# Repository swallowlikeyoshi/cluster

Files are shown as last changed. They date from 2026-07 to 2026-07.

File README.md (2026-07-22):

# HEVEN Cluster 펌웨어

**2026 영광 대회 · 계기 클러스터(Instrument Cluster)** — ESP32가 CAN/BLE로 차량 상태(속도·전압·SOC·온도·에러)를 **받아서** LCD에 표현하고, 계기판 버튼 입력을 VCU로 보냅니다. VESS 신호 경로와 스위칭은 클러스터 ESP32 GPIO 입력에서 분리합니다. VCU와 달리 **안전 임계가 약한 표시 전용 보드**입니다.

> 🤖 **AI 에이전트/팀원은 [`AGENTS.md`](AGENTS.md)를 먼저 읽으세요** — 무엇을 고쳐도 되고 무엇을 건드리면 안 되는지 규칙이 있습니다.

---

## 한눈에

- **스택**: PlatformIO + Arduino-ESP32, TWAI(CAN), ILI9341 LCD. 화면은 **패널 독립적 1bpp 프레임버퍼**(위젯이 그림) + `display_blit`(ILI9341로 blit)
- **구조**: 잠긴 코어(CAN·프레임버퍼·blit) + 팀원이 채우는 순수 모듈(`src/modules/`). VCU와 **동일한 2층 설계**지만 안전 FSM·50ms 라이프 태스크가 없고 CAN은 **수신(RX) 위주**입니다.
- **상태**: ESP32 빌드 그린, 호스트 테스트 39개 통과

## 빠른 시작

```bash
# 1. 이 레포를 깨끗한 위치에 클론
git clone https://github.com/2026-HEVEN/cluster.git
cd cluster

# 2. PlatformIO 설치 (한 번만) — VS Code면 PlatformIO IDE 확장 설치로 대체 가능
uv tool install platformio      # 또는: pipx install platformio

# 3. 노트북에서 테스트 (하드웨어 불필요)
pio test -e native

# 4. 보드에 빌드 & 업로드 (ESP32 연결 상태에서)
pio run -e esp32dev -t upload
```

> 🧪 **테스트가 처음이거나 Windows 사용자라면** → 노션 [펌웨어 테스트 실행 방법](https://www.notion.so/390913e532e68199a9b5e340b73e9e71) 참고. AI에 복붙할 프롬프트 + "이렇게 나오면 성공" 출력 예시 + Windows(WSL2/MinGW) 셋업까지 있습니다. (보드 업로드는 Windows도 그냥 되고, `native` 단위테스트만 host 컴파일러가 필요해요.)

> ℹ️ 모터컨트롤러 값은 MCU→VCU 피드백 프레임을 Cluster가 같은 CAN 버스에서 수신합니다. BMS SOC는 `LWS-1608` BLE BMS에 Cluster ESP32가 직접 연결해 표시용 telemetry로만 읽습니다.

## 어디서 작업하나

| 폴더 | 내용 | 편집? |
|---|---|---|
| `src/modules/` | 순수 계산 함수 `xxx_compute()` | ✅ **여기서만** |
| `test/` | 노트북 단위 테스트 | ✅ |
| `src/core/`, `src/logic/`, `include/` | CAN·framebuffer·display_blit·스케줄러·타입 | 🔒 잠김 |
| `platformio.ini`, `src/main.cpp` | 빌드 설정·진입점 | 🔒 잠김 |

새 모듈을 추가하거나 기존 `compute()`를 채우는 법 → [`docs/ADDING_A_MODULE.md`](docs/ADDING_A_MODULE.md)

## 모듈 목록 (FILL-IN)

- `hmi_input` — config 스위치(패독·TC·회생·디버그) → `ClusterCommand` (CAN으로 VCU에 전송)
- `widgets/` — 계기판 화면 위젯 (speed·battery·warnings·gear ...). 1bpp 프레임버퍼에 그림.
  새 위젯 추가법: `docs/ADDING_A_WIDGET.md`

> 표시는 패널 독립적 **1bpp 프레임버퍼**로. 실제 패널 blit(`display_blit`)은 하드웨어 확정 후 구현.

## 문서

| 문서 | 내용 |
|---|---|
| [`AGENTS.md`](AGENTS.md) / `CLAUDE.md` | 작업 규칙 (에이전트·팀원 필독) |
| [`docs/ADDING_A_MODULE.md`](docs/ADDING_A_MODULE.md) | 모듈 추가/작성 절차 |
| [`docs/CAN_PROTOCOL.md`](docs/CAN_PROTOCOL.md) | CAN 메시지 명세 (VCU/Cluster 공유 단일 출처) |

> 전체 설계 원리(compute/update 분리, state 격리, 테스트 등)는 **VCU 레포의 [`ARCHITECTURE.md`](https://github.com/2026-HEVEN/vcu/blob/main/docs/ARCHITECTURE.md)** 와 동일합니다.

## 아직 미구현 (의도된 TODO)

- **VCU 표시 상태 프레임 구현** — VCU가 `0x1801C0D0`으로 확정 기어/HV/브레이크 상태를 보내면 Cluster가 그 값을 우선 표시합니다.
- **BMS BLE 실차 검증** — `LWS-1608` BLE 이름, `FFE0/FFE1/FFE2` 특성, SOC/current 부호를 실제 배터리팩에서 확인해야 합니다.

## 버전 기록 (Changelog)

> 각 버전은 git 태그로도 관리됩니다 → [GitHub Releases](https://github.com/2026-HEVEN/cluster/releases)
> **새 버전 올릴 때:** 아래에 항목 추가 → `git tag vX.Y` → `git push origin vX.Y`.

### v1.1.1 (2026-07-06) — 위젯 레이아웃 렌더 테스트
- `test/test_render_layout`: `app_wiring.cpp`의 위젯 배치를 그대로 재현해 24bit BMP로 덤프하는 시각화 테스트 추가. `pio test -e native -f test_render_layout` 로 실행 → `render_layout.bmp` 생성(Windows 사진 앱/그림판 등 추가 도구 없이 바로 열림), 위젯별 할당 공간을 박스로 표시
- `.gitignore`에 `*.bmp` 추가

### v1.1 (2026-06-29) — 디스플레이 프레임버퍼 재설계
- 패널 독립적 **1bpp 프레임버퍼**(320×160) + 위젯 모듈(speed · battery · warnings · gear) 도입 — 렌더링을 모듈로 넘겨 자유도↑, host 테스트 가능(ASCII 시각화)
- `hmi_input` → **`ClusterCommand`**(paddock · TC · regen · debug) 의미 커맨드 패턴, **패독 모드** 추가
- **제거**: `vess`, `indicators`, `display_render`(U8g2), `io_expander`(MCP23017)
- `display_blit` stub(패널 확정 후 구현), CAN 커맨드 레이아웃(`CAN_PROTOCOL.md` §5.7) 갱신

### v1.0 (2026-06-29) — 초기 Cluster 펌웨어 베이스
- 잠긴 코어(CAN RX · MCP23017 · U8g2 OLED) + 순수 모듈(display · indicators · vess · hmi_input)
- PlatformIO native 테스트, AGENTS/ADDING_A_MODULE/CAN_PROTOCOL 문서

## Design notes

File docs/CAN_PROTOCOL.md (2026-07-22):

# HEVEN CAN 프로토콜 명세서 (단일 출처)

> **이 문서는 VCU·Cluster 양 레포가 공유하는 단일 출처(single source of truth)입니다.**
> 코드(`include/can_protocol.h`)와 이 문서는 항상 일치해야 하며, 수정 시 **양 레포에 동일하게 반영**합니다. (담당: 김도현)
> 출처: `EZkontrol-CANBUS-MCU-to-VCU.pdf V1.0`, `EZkontrol-CANBUS-MCU-to-METER.pdf V1.1`, 시스템 설계.

---

## 1. 버스 파라미터

| 항목 | 값 |
|---|-----|
| 비트레이트 | **250 kbps** |
| 프레임 | CAN 2.0B **확장(29비트) 식별자** |
| 바이트 순서 | **리틀엔디언** (예: 0x1234 → 0x34 먼저, 0x12 나중) |
| 토폴로지 | 데이지체인, 양 끝단 120Ω 종단 |
| 표준 | SAE J1939 기반 |

---

## 2. 29비트 식별자 구조 (J1939)

```
 28..26   25   24   23..16     15..8       7..0
┌────────┬────┬────┬────────┬──────────┬────────────┐
│PRIORITY│ R  │ DP │  PF    │   PS     │     SA     │
│ 3bit   │ 0  │ 0  │ 8bit   │  8bit    │   8bit     │
└────────┴────┴────┴────────┴──────────┴────────────┘
```
- **PRIORITY**: 0~7 (값 작을수록 우선). 제어명령=3, 피드백=6.
- **PF (PDU Format)**: 메시지 종류. PF<240이면 PS=목적지 주소(DA), PF≥240이면 PS=그룹확장.
- **PS**: 목적지 노드 주소 (PF<240일 때).
- **SA**: 송신 노드 주소.

> 예) `0x0C01EFD0` → PRIORITY=3, PF=0x01, PS=0xEF(MCU1 목적지), SA=0xD0(VCU 송신).
> 즉 **"VCU가 MCU1에게 보내는 1번 메시지"**.

---

## 3. 노드 주소 (SA)

### HEVEN 시스템에서 실제 사용

| 노드 | SA (HEX) | SA (DEC) | 비고 |
|---|---|---|---|
| Energy_Meter / **METER** | 0x17 | 23 | EZkontrol 표준 계기 주소 |
| **Cluster_ESP32** | 0xC0 | 192 | 계기판 HMI (시스템 설계) |
| **VCU_ESP32** | 0xD0 | 208 | 차량 제어 |
| **Controller_L (MCU1)** | 0xEF | 239 | 좌측 모터컨트롤러 (기본값) |
| **Controller_R (MCU2)** | 0xF0 | 240 | 우측 — **EZkontrol 앱에서 SA=0xF0 수동 설정 필요** |

### EZkontrol 표준 전체 주소표 (참고)

| 노드 | 주소 |
|---|---|
| METER | 23 (0x17) |
| VCU | 208 (0xD0) |
| MCU1~4 | 239~242 (0xEF~0xF2) |
| BMS1~4 | 243~246 (0xF3~0xF6) |
| GLOBAL | 255 (0xFF) |

> **N.B.** MCU의 SA는 호스트(EZkontrol 앱)에서 "controller number"로 설정. 기본 SA = 239(0xEF).
> Controller_R은 반드시 240(0xF0)으로 바꿔야 좌우가 충돌하지 않음.

---

## 4. 메시지 ID 일람 (HEVEN)

| 방향 | 메시지 | Controller_L (0xEF) | Controller_R (0xF0) | 주기 | Prio |
|---|---|---|---|---|---|
| VCU → MCU | 제어명령 / 핸드셰이크응답 | `0x0C01EFD0` | `0x0C01F0D0` | 50ms | 3 |
| MCU → VCU | 피드백 Part I (전압/전류/속도) | `0x1801D0EF` | `0x1801D0F0` | 50ms | 6 |
| MCU → VCU | 피드백 Part II (온도/상태/에러) | `0x1802D0EF` | `0x1802D0F0` | 50ms | 6 |
| MCU → METER | 계기 메시지 I | `0x180117EF` | `0x180117F0` | 100ms | 6 |
| MCU → METER | 계기 메시지 II | `0x180217EF` | `0x180217F0` | 100ms | 6 |
| Cluster → VCU | 커맨드 (패독/TC/회생/디버그) | `0x1801D0C0` (신규) | — | 100ms | 6 |
| Cluster → TMA-1/logger | BMS 상태 요약 | `0x18F3FFC0` (신규) | — | 100ms | 6 |
| Cluster → TMA-1/logger | BMS 상세 요약 | `0x18F4FFC0` (신규) | — | 100ms | 6 |

> ID에서 PS(목적지)·SA(송신)만 컨트롤러별로 바뀜. 위 표의 ID는 `PF<<16 | PS<<8 | SA`로 조립됨(+ Priority).

---

## 5. 메시지 상세

### 5.1 VCU → MCU : 제어명령  `0x0C01EFD0` (L) / `0x0C01F0D0` (R) · 50ms

| 바이트 | 항목 | 분해능 | 오프셋 | 범위 |
|---|---|---|---|---|
| 0~1 | Target Phase Current (토크) | 0.1 A/bit | −3200 A | −3200~3200 A |
| 2~3 | Target Speed | 1 rpm/bit | −32000 | −32000~32000 rpm |
| 4 | Command Controls | — | — | bit0: 0=HALTED / 1=RUNNING<br>bit1: 0=토크모드 / 1=속도모드<br>bit7-2: 예약 |
| 5,6 | 예약 | — | — | 0 |
| 7 | Life signal | — | — | 0~0xFF (매 프레임 +1) |

**토크 스케일링**: `raw16 = (target_A + 3200) × 10` (리틀엔디언). 음수 = 회생제동.
→ 0A=32000, +32A=32320, −32A=31680. **`include/can_protocol.h`의 `torque_to_raw()`와 동일.**

### 5.2 VCU → MCU : 핸드셰이크 응답  `0x0C01EFD0` / `0x0C01F0D0`

8바이트 **전부 `0xAA`**. (MCU의 0x55 요청에 대한 응답 — §6 참고)

### 5.3 MCU → VCU : 피드백 Part I  `0x1801D0EF` (L) / `0x1801D0F0` (R) · 50ms

| 바이트 | 항목 | 분해능 | 오프셋 | 범위 |
|---|---|---|---|---|
| 0~1 | Bus Voltage | 0.1 V/bit | 0 | 0~300 V |
| 2~3 | Bus Current | 0.1 A/bit | −3200 A | −3200~3200 A |
| 4~5 | Phase Current | 0.1 A/bit | −3200 A | −3200~3200 A |
| 6~7 | Speed | **1 rpm/bit** | −32000 | −32000~32000 rpm |

### 5.4 MCU → VCU : 피드백 Part II  `0x1802D0EF` (L) / `0x1802D0F0` (R) · 50ms

| 바이트 | 항목 | 분해능 | 오프셋 |
|---|---|---|---|
| 0 | Controller Temperature | 1 ℃/bit | −40 ℃ |
| 1 | Motor Temperature | 1 ℃/bit | −40 ℃ |
| 2 | STATUS — bit0: HALTED/RUNNING, bit1: 토크/속도모드 | — | — |
| 3 | ERROR1 비트맵 (아래) | — | — |
| 4 | ERROR2 비트맵 (아래) | — | — |
| 5 | ERROR3 비트맵 (아래) | — | — |
| 6 | 예약 | — | — |
| 7 | Life signal | — | 0~0xFF |

**ERROR 비트맵** (각 비트 0=정상 / 1=에러):
- **Byte3**: 0 과전류, 1 과부하, 2 과전압, 3 저전압, 4 컨트롤러과열, 5 모터과열, 6 모터스톨, 7 모터결상
- **Byte4**: 0 모터센서, 1 모터보조센서, 2 엔코더정렬불량, 3 폭주방지작동, 4 메인가속, 5 보조가속, 6 프리차지, 7 DC컨택터
- **Byte5**: 0 전력밸브, 1 전류센서, 2 오토튠, 3 RS485, 4 CAN, 5 소프트웨어

### 5.5 MCU → METER : 계기 메시지 I  `0x180117EF` · 100ms

> Cluster가 METER(0x17)로 동작할 때 직접 수신 (§7 경로 결정 참고).

| 바이트 | 항목 | 분해능 | 오프셋 |
|---|---|---|---|
| 0~1 | Bus Voltage | 0.1 V/bit | 0 |
| 2~3 | Bus Current | 0.1 A/bit | −3200 A |
| 4~5 | Phase Current | 0.1 A/bit | −3200 A |
| 6~7 | Speed | **0.1 rpm/bit** ⚠️ | −32000 |

> ⚠️ **METER 경로의 Speed는 0.1rpm/bit** — VCU 경로(5.3, 1rpm/bit)와 분해능이 다르다. 혼동 주의.
> (PDF 본문의 PS 표기 "0x11"은 오타이며, ID값 `0x180117EF`가 정답 — PS=0x17=METER.)

### 5.6 MCU → METER : 계기 메시지 II  `0x180217EF` · 100ms

| 바이트 | 항목 | 분해능/의미 |
|---|---|---|
| 0 | Controller Temperature | 1 ℃/bit, offset −40 |
| 1 | Motor Temperature | 1 ℃/bit, offset −40 |
| 2 | Accelerator Opening | 1 %/bit (0~100%) |
| 3 | STATUS — bit2-0 Gear(0:N/A,1:R,2:N,3:D1,4:D2,5:D3,6:S,7:P), bit3 Brake(0/1), bit6-4 Operation Mode(2:Cruise,3:EBS,4:Hold), bit7 DC Contactor(0:OFF/1:ON) | — |
| 4 | ERROR1 (5.4 Byte3과 동일 비트맵) | — |
| 5 | ERROR2 (5.4 Byte4와 동일) | — |
| 6 | ERROR3 (5.4 Byte5와 동일) | — |
| 7 | bit7-4: Life signal | 0~0xFF |

### 5.7 Cluster → VCU : 커맨드  `0x1801D0C0` (신규 할당) · 100ms

> 계기판 config 버튼(패독·TC·회생제동·디버그)을 VCU에 전달. **EZkontrol 표준이 아닌 HEVEN 자체 정의.**
> 기어 스위치는 Cluster ESP32에 직접 연결하지 않고 VCU 쪽 ADC/pass-through 회로에서 읽는다.
> PF=0x01, PS=0xD0(VCU), SA=0xC0(Cluster). MCU→VCU(0x1801D0EF)와 SA로 구분되어 충돌 없음.
> 인코딩 구현: Cluster 펌웨어 `encode_cluster_command()`. 아래 레이아웃과 일치.

| 바이트 | 항목 | 의미 |
|---|---|---|
| 0 | Reserved | 0 |
| 1 | Config flags | bit0: TC enabled, bit2-1: Regen level(0~3), bit3: Debug enabled, bit7-4: reserved(0) |
| 2 | Flags | bit0: Paddock request, bit7-1: reserved(0) |
| 3~7 | 예약 | 0 |

> ⚠️ 패독은 **요청 신호**일 뿐. VCU가 토크/속도를 상한 이하로 클램프하고 CAN 끊김 시 fail-safe(제한 유지)를 결정해야 함.
> VESS 스위칭은 Cluster GPIO25 입력과 이 CAN 커맨드에서 제외한다. VESS 신호 경로/스위칭은 별도 하드웨어 또는 VCU 쪽 계약으로 관리한다.

### 5.8 VCU → Cluster : 표시 상태  `0x1801C0D0` (HEVEN 정의) · 50~100ms 권장

> Cluster가 스위치 입력값이 아니라 **VCU가 확정한 차량 상태**를 표시하기 위한 프레임.
> 현재 Cluster 펌웨어는 이 프레임이 들어오면 기어/HV/브레이크를 갱신한다. SOC는 선택 사항이며, 현재 주 경로는 Cluster의 BLE BMS 직접 수신이다.
> VCU 쪽 구현 전에는 Cluster가 기어를 확정할 수 없으므로 기본 N 표시로 남는다.

| 바이트 | 항목 | 의미 |
|---|---|---|
| 0 | Gear display | 0:N, 1:R, 2:D, 3:P |
| 1 | Flags | bit0: Brake, bit1: HV active, bit2: SOC valid |
| 2 | SOC percent | 0~100, bit2(SOC valid)=1일 때만 유효 |
| 3~6 | 예약 | 0 |
| 7 | Life signal | 0~0xFF |

> BMS SOC는 현재 `LWS-1608` BLE BMS를 Cluster ESP32가 직접 polling해서 표시한다.
> VCU가 추후 SOC를 확정값으로 보내야 하는 경우에만 이 프레임의 `SOC valid`와 `SOC percent`를 사용한다. VCU 프레임에서 SOC valid가 0이어도 BLE로 받은 SOC는 지우지 않는다.

### 5.9 Cluster → TMA-1/logger : BMS 상태 요약 `0x18F3FFC0` (HEVEN 정의) · 100ms

> Cluster가 BLE로 직접 수신한 LWS-1608 BMS 표시용 정보를 TMA-1/logger에 전달한다.
> 이 프레임은 **차량 제어용 안전판단에 사용하지 않는다.** BLE가 끊기면 valid bit가 0으로 내려가며, 수신기는 해당 값을 stale/display-only로 취급한다.
> PF=0xF3, PS=0xFF, SA=0xC0. Broadcast 성격이므로 TMA-1/logger는 버스에서 수신만 하면 된다.

| 바이트 | 항목 | 분해능/의미 |
|---|---|---|
| 0 | Flags | bit0: BMS data valid, bit1: BLE connected, bit7-2: reserved(0) |
| 1 | SOC | 1 %/bit, 0~100 |
| 2~3 | Pack voltage | 0.1 V/bit, little-endian |
| 4~5 | Pack current | 0.1 A/bit, offset −3200 A, little-endian |
| 6 | BMS temperature | 1 ℃/bit, offset −40 ℃ |
| 7 | Life signal | 0~255 |

### 5.10 Cluster → TMA-1/logger : BMS 상세 요약 `0x18F4FFC0` (HEVEN 정의) · 100ms

| 바이트 | 항목 | 분해능/의미 |
|---|---|---|
| 0 | Flags | bit0: BMS data valid, bit1: BLE connected, bit7-2: reserved(0) |
| 1 | SOH | 1 %/bit, 0~100 |
| 2~3 | Remaining capacity | 1 mAh/bit, little-endian |
| 4~5 | Cycle count | 1 cycle/bit, little-endian |
| 6 | Reserved | 0 |
| 7 | Life signal | 0~255 |

---

## 6. 핸드셰이크 & 타임아웃 (EZkontrol 규칙)

```
[전원 ON]
   │  MCU가 0x1801D0EF 로 8바이트 0x55 를 50ms(20Hz)마다 송신
   ▼
VCU가 0x55 수신 ──► VCU가 0x0C01EFD0 로 8바이트 0xAA 응답
   │
   ▼  핸드셰이크 성립
MCU: 메시지 I·II 송신 시작 + VCU 제어명령(메시지 I) 대기·실행
```

**통신 실패 판정 (MCU 측):**
- VCU 제어명령(0x0C01EFD0)을 **10회 연속** 못 받거나
- Life signal **5회 연속** 실패

→ MCU 셧다운 후 핸드셰이크 재시도. (그래서 VCU는 50ms 라이프/제어 프레임을 **절대 끊지 말 것** — 펌웨어의 전용 FreeRTOS 라이프 태스크가 이를 보장.)

---

## 7. 계기 데이터 수신 경로 — **확정: C. VCU 모드 수신 스니핑**

EZkontrol 컨트롤러는 **METER 모드**일 때 피드백을 `0x1801xxEF`(VCU용)가 아니라
`0x180117EF`/`0x180217EF`(METER용, §5.5/5.6)로 보낸다.

~~A. Cluster=METER 직수신~~ / ~~B. VCU 게이트웨이~~ 대신 다음 경로로 확정:

**C. 컨트롤러를 VCU 모드로 설정 → Cluster가 그 VCU행 프레임(`0x1801D0EF/F0`, `0x1802D0EF/F0`)을 같은 버스에서 그대로 수신(스니핑)한다.**

- CAN은 멀티드롭 버스라 VCU 목적지로 보낸 프레임도 버스에 물린 모든 노드(Cluster 포함)에 물리적으로 도달한다.
  Cluster는 그 프레임을 **읽기만** 하면 되고, VCU의 게이트웨이 재방송이나 컨트롤러의 METER 모드 설정이 필요 없다.
- **필수 사전조건**: 두 컨트롤러 모두 EZkontrol 앱에서 VCU 모드로 설정, Controller_R은 SA=0xF0으로 설정.
  (METER 모드로 남아있으면 Cluster는 아무 것도 못 받는다 — `0x1801D0xx`가 아니라 `0x180117xx`로 나가기 때문.)
- Cluster는 컨트롤러 피드백을 **재방송하지 않고 읽기만** 한다. 단, 자체 HMI/BMS 정보는 별도 HEVEN 정의 프레임(`CAN_ID_CLUSTER_CMD`, `CAN_ID_CLUSTER_BMS_STATUS`, `CAN_ID_CLUSTER_BMS_DETAIL`)으로 송신한다.
- 구현: `src/core/can_bus.cpp`의 `poll_rx()`가 `CAN_ID_FB1_L/R`, `CAN_ID_FB2_L/R`을 필터링해 `state`의 `_r` 접미사 필드(Controller_R)와 기본 필드(Controller_L)에 각각 채운다.
- 기어/HV처럼 VCU가 최종 확정해야 하는 표시값은 `CAN_ID_VCU_CLUSTER_STATUS`(0x1801C0D0)를 통해 받는다. SOC는 현재 BLE BMS 직접 수신을 우선 사용한다.

---

## 8. 코드 매핑 (`include/can_protocol.h`)

현재 구현된 것:
```cpp
constexpr uint32_t CAN_ID_TORQUE_L = 0x0C01EFD0;  // VCU→MCU1
constexpr uint32_t CAN_ID_TORQUE_R = 0x0C01F0D0;  // VCU→MCU2
uint16_t torque_to_raw(float amps);   // (amps+3200)*10
float    raw_to_torque(uint16_t raw);
// SA 상수: SA_VCU=0xD0, SA_CLUSTER=0xC0, SA_CONTROLLER_L=0xEF, SA_CONTROLLER_R=0xF0, SA_ENERGY_METER=0x17

// 피드백 ID (VCU행 프레임을 Cluster가 스니핑, §7)
constexpr uint32_t CAN_ID_FB1_L = 0x1801D0EF;   // Part I (전압/전류/속도)
constexpr uint32_t CAN_ID_FB2_L = 0x1802D0EF;   // Part II (온도/상태/에러)
constexpr uint32_t CAN_ID_FB1_R = 0x1801D0F0;
constexpr uint32_t CAN_ID_FB2_R = 0x1802D0F0;
constexpr uint32_t CAN_ID_CLUSTER_CMD = 0x1801D0C0;
constexpr uint32_t CAN_ID_VCU_CLUSTER_STATUS = 0x1801C0D0;
constexpr uint32_t CAN_ID_CLUSTER_BMS_STATUS = 0x18F3FFC0;
constexpr uint32_t CAN_ID_CLUSTER_BMS_DETAIL = 0x18F4FFC0;

// 디코더: raw_to_voltage(×0.1), raw_to_current(×0.1,-3200), raw_to_temp(-40), raw_to_speed(1rpm/bit,-32000)
// RX 파싱 구현: src/core/can_bus.cpp poll_rx() — state의 기본 필드=Controller_L, `_r` 접미사=Controller_R
```

METER 경로(§5.5/5.6, 0.1rpm/bit)는 이 설계에서 사용하지 않는다 — 컨트롤러가 VCU 모드로 고정되므로 필요 없음.

---

## 9. 변경 관리

- 이 파일과 `include/can_protocol.h`는 **글자 단위로 일치**해야 한다.
- 수정 시: ① 이 문서 갱신 → ② 양 레포의 `can_protocol.h` 동기화 → ③ 변경 요약을 팀 공지.
- 새 메시지 ID는 J1939 규칙(PF/PS/SA)에 맞게 할당하고 §4 표에 추가.

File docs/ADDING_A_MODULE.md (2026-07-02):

# 새 모듈 추가하기 (팀원용 가이드 · Cluster)

이 펌웨어는 **잠긴 코어**와 **여러분이 채우는 모듈(`src/modules/`)** 로 나뉩니다.
여러분은 `src/modules/` 안의 `*_compute()` 함수만 작성합니다.
CAN 수신·디스플레이·IO는 코어가 처리합니다. (Cluster는 안전 FSM/라이프 태스크가 없습니다.)

> 계기판 **화면 위젯**을 추가하려면 → `ADDING_A_WIDGET.md` 를 보세요.

## 규칙 (꼭 지키기)
- 모듈 파일(`src/modules/*`)에서 `state.h` 와 `<Arduino.h>` 를 **include 하지 않는다.**
- 값은 `types.h` 의 도메인 타입(`Percent`, `Unit`, `Rpm` ...)으로 받고 돌려준다 — 범위가 자동으로 지켜진다.
- 계산에 이력(필터/적분)이 필요하면 **전역변수 대신 상태 struct를 인자로** 받는다 (`hmi_input.h` 의 `hmi_compute` 가 `prev_buttons` 를 인자로 받아 엣지 검출하는 방식 참고).

## 1. 모듈 만들기 (.h / .cpp 한 쌍)
`src/modules/coolant.h`
```cpp
#pragma once
#include "types.h"
struct CoolantInput  { int raw_adc; };
struct CoolantOutput { float temp_c; bool fan_on; };
CoolantOutput coolant_compute(const CoolantInput &in);   // 순수 함수
```
`src/modules/coolant.cpp`
```cpp
#include "modules/coolant.h"
CoolantOutput coolant_compute(const CoolantInput &in) {
    float t = in.raw_adc * 0.05f;          // TODO: 실제 변환식
    return { t, t > 80.0f };
}
```

## 2. 테스트 먼저/같이 쓰기 (하드웨어 없이 노트북에서)
`test/test_coolant/test_coolant.cpp`
```cpp
#include <unity.h>
#include "modules/coolant.h"
void test_fan_turns_on_when_hot(void) {
    TEST_ASSERT_TRUE(coolant_compute({2000}).fan_on);
}
void setUp(void){} void tearDown(void){}
int main(int,char**){ UNITY_BEGIN(); RUN_TEST(test_fan_turns_on_when_hot); return UNITY_END(); }
```
실행: `pio test -e native -f test_coolant`

## 3. 공유 상태에 필드 추가 (코어 담당자에게 요청 or 직접)
`include/state.h` 의 `ClusterState` 에 필요한 필드를 추가한다. 예: `bool fan_on;`

## 4. 배선 한 줄 + 스케줄 한 줄 (코어 담당자 영역)
`src/core/app_wiring.cpp`:
```cpp
static void coolant_update() {
    CoolantOutput o = coolant_compute({ analogRead(PIN_COOLANT_ADC) });
    state.fan_on = o.fan_on;
}
// g_tasks[] 배열에 한 줄 추가:
{ my_update, 50, 0 },  // 20 Hz
```

## 5. 설정·상태가 있는 센서(PCNT/SPI/I2C/타이머)는?
직접 `analogRead` 한 줄로 안 되는 페리페럴은 **잠긴 드라이버**를 `src/core/drivers/` 에 만들고
(예: `wss_driver`), 모듈의 `compute()` 는 그 드라이버가 준 깔끔한 원시값만 변환한다.
드라이버 인터페이스(.h)는 코어 담당자와 함께 정한다.

## 체크리스트
- [ ] `*_compute()` 가 `state.h`/`Arduino.h` 를 include 하지 않는다
- [ ] 입출력 타입이 모듈 헤더(.h)의 계약과 일치한다 (도메인 타입 `Percent` 등은 선택)
- [ ] `pio test -e native -f test_<name>` 통과
- [ ] `app_wiring.cpp` 에 `*_update()` + `g_tasks[]` 한 줄 추가
- [ ] `pio run -e esp32dev` 빌드 성공

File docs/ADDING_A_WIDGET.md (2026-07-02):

# 새 계기판 위젯 추가하기

계기판 화면은 **위젯 여러 개**로 그려집니다. 각 위젯 = 순수 함수로, 공유 **1bpp 프레임버퍼**의
자기 영역에 그림만 그립니다. 하드웨어·CAN·전역상태를 모르므로 **노트북에서 그대로 테스트**됩니다.

## 1. 위젯 파일 만들기 (`src/modules/widgets/`)
`widget_range.h`
```cpp
#pragma once
#include "framebuffer.h"
void widget_range_draw(FrameBuffer &fb, int x, int y, int range_km);
```
`widget_range.cpp`
```cpp
// [FILL-IN] Edit this file. Draw your widget into the framebuffer.
#include "modules/widgets/widget_range.h"
void widget_range_draw(FrameBuffer &fb, int x, int y, int range_km) {
    fb_number(fb, x, y, range_km, 2);
}
```

## 2. 그리기 도구 (framebuffer.h)
- `fb_rect(fb, x, y, w, h, fill, on)` / `fb_hline` / `fb_vline`
- `fb_text(fb, x, y, "R", scale)` — 폰트 글리프는 `font5x7.cpp`에 있는 문자만( ` 0-9 - R N D %`). 새 문자가 필요하면 코어 담당에게 글리프 추가 요청.
- `fb_number(fb, x, y, value, scale)` / `fb_bar(fb, x, y, w, h, pct)`

## 3. 테스트 (하드웨어 없이)
`test/test_widget_range/test_widget_range.cpp` — 프레임버퍼에 예상 픽셀이 켜졌는지 단언.
실행: `pio test -e native -f test_widget_range`.
디버깅 팁: 실패 시 `fb.get(x,y)` 를 루프 돌려 `#`/`.` 로 찍어 화면을 눈으로 확인.

## 4. 화면에 배치 (코어 담당 영역)
`src/core/app_wiring.cpp` 의 `display_update()` 에 한 줄 추가:
```cpp
widget_range_draw(fb, 10, 60, computed_range);
```
좌표(영역)는 다른 위젯과 겹치지 않게 코어 담당이 조율.

## 규칙
- 위젯 `.cpp` 에서 `state.h` / `<Arduino.h>` include 금지 (컴파일 깨짐 = 의도된 방어).
- 자기 영역 밖으로 그려도 프레임버퍼가 클리핑하지만, 레이아웃은 지킬 것.

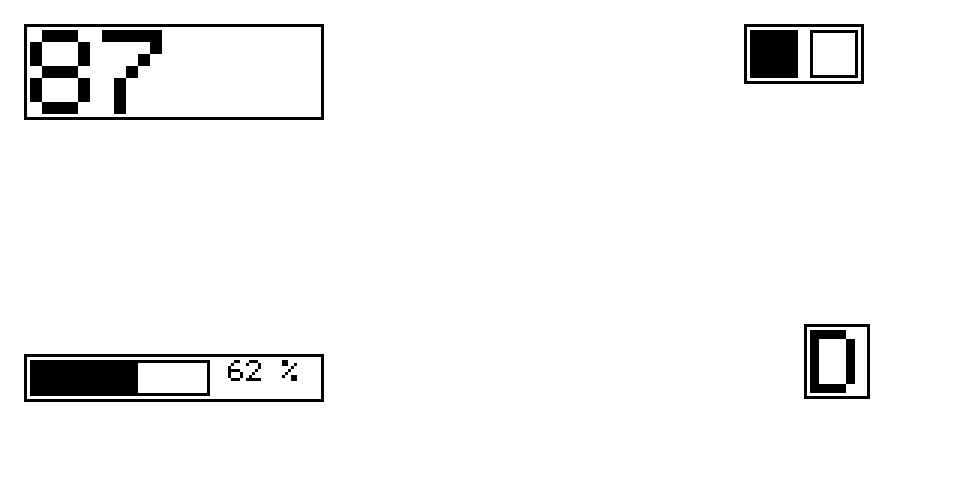
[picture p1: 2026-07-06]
docs/widget_layout_example.png

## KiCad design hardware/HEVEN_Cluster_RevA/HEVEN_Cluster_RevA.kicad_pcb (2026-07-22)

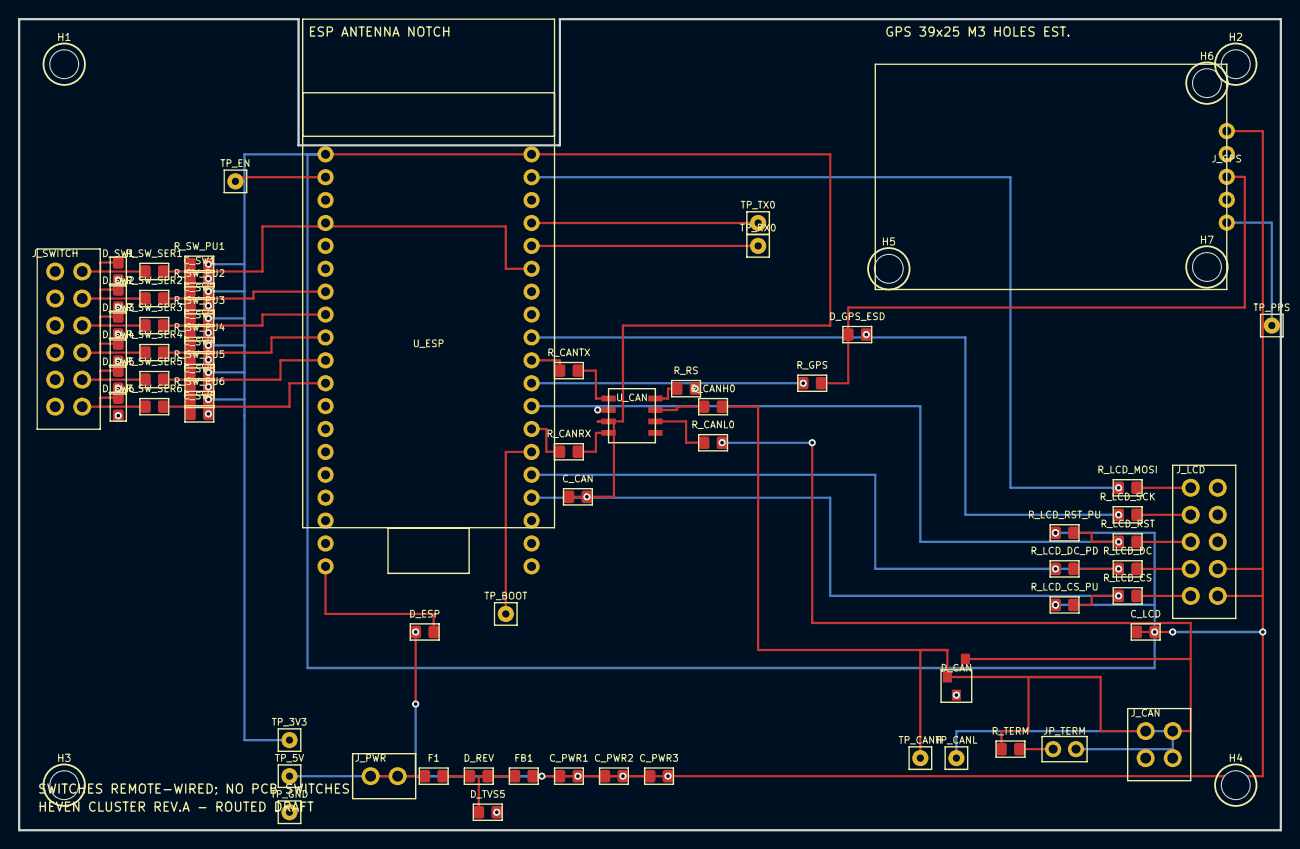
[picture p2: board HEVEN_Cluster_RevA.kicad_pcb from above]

Board: 2 copper layers, 140.0 x 90.0 mm, 76 parts (0 on the bottom side), 46 nets.

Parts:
C_CAN: 100nF; C_CAN
C_LCD: 10uF; C_LCD
C_PWR1: 100uF; C_PWR1
C_PWR2: 10uF; C_PWR2
C_PWR3: 100nF; C_PWR3
C_SW1: 100nF; C_SW1
C_SW2: 100nF; C_SW2
C_SW3: 100nF; C_SW3
C_SW4: 100nF; C_SW4
C_SW5: 100nF; C_SW5
C_SW6: 100nF; C_SW6
D_CAN: PESD1CAN; D_CAN
D_ESP: SS34; D_ESP
D_GPS_ESD: PESD3V3; D_GPS_ESD
D_REV: SS34; D_REV
D_SW1: PESD3V3; D_SW1
D_SW2: PESD3V3; D_SW2
D_SW3: PESD3V3; D_SW3
D_SW4: PESD3V3; D_SW4
D_SW5: PESD3V3; D_SW5
D_SW6: PESD3V3; D_SW6
D_TVS5: SMBJ5.0A; D_TVS5
F1: PTC 1.1A; F1
FB1: Ferrite 600R; FB1
H1, H2, H3, H4: M3_MAIN; MountingHole
H5, H6, H7: M3_GPS_EST; MountingHole
JP_TERM: 120R ENABLE; JP_TERM
J_CAN: Molex 43045-0412 CAN; J_CAN
J_GPS: SZH-NEO03 1x5 RA socket; J_GPS
J_LCD: Molex 43045-1012, LCD cable; J_LCD
J_PWR: Molex 43045-0212 regulated 5V input; J_PWR
J_SWITCH: Molex 43045-1212, 6 signal/GND pairs; J_SWITCH
R_CANH0: 0R; R_CANH0
R_CANL0: 0R; R_CANL0
R_CANRX: 33R; R_CANRX
R_CANTX: 33R; R_CANTX
R_GPS: 1k; R_GPS
R_LCD_CS: 33R; R_LCD_CS
R_LCD_CS_PU: 10k; R_LCD_CS_PU
R_LCD_DC: 33R; R_LCD_DC
R_LCD_DC_PD: 100k; R_LCD_DC_PD
R_LCD_MOSI: 33R; R_LCD_MOSI
R_LCD_RST: 33R; R_LCD_RST
R_LCD_RST_PU: 10k; R_LCD_RST_PU
R_LCD_SCK: 33R; R_LCD_SCK
R_RS: 10k; R_RS
R_SW_PU1: 10k; R_SW_PU1
R_SW_PU2: 10k; R_SW_PU2
R_SW_PU3: 10k; R_SW_PU3
R_SW_PU4: 10k; R_SW_PU4
R_SW_PU5: 10k; R_SW_PU5
R_SW_PU6: 10k; R_SW_PU6
R_SW_SER1: 1k; R_SW_SER1
R_SW_SER2: 1k; R_SW_SER2
R_SW_SER3: 1k; R_SW_SER3
R_SW_SER4: 1k; R_SW_SER4
R_SW_SER5: 1k; R_SW_SER5
R_SW_SER6: 1k; R_SW_SER6
R_TERM: 120R; R_TERM
TP_3V3: TP; TP_3V3
TP_5V: TP; TP_5V
TP_BOOT: TP; TP_BOOT
TP_CANH: TP; TP_CANH
TP_CANL: TP; TP_CANL
TP_EN: TP; TP_EN
TP_GND: TP; TP_GND
TP_PPS: TP; TP_PPS
TP_RX0: TP; TP_RX0
TP_TX0: TP; TP_TX0
U_CAN: SN65HVD230D; U_CAN
U_ESP: YD-ESP32 USB-C Core Board; U_ESP

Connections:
3V3: C_CAN.1, R_LCD_CS_PU.1, R_LCD_RST_PU.1, R_SW_PU1.2, R_SW_PU2.2, R_SW_PU3.2, R_SW_PU4.2, R_SW_PU5.2, R_SW_PU6.2, TP_3V3.1, U_CAN.3, U_ESP.1
5V_FUSED: D_REV.1, F1.2
5V_IN: F1.1, J_PWR.1
5V_PROT: D_REV.2, D_TVS5.1, FB1.1
5V_SYS: C_LCD.1, C_PWR1.1, C_PWR2.1, C_PWR3.1, D_ESP.1, FB1.2, J_GPS.1, J_LCD.8, J_LCD.10, TP_5V.1
CAN_H: D_CAN.1, J_CAN.1, R_CANH0.2, R_TERM.1, TP_CANH.1
CAN_H_INT: R_CANH0.1, U_CAN.7
CAN_L: D_CAN.3, JP_TERM.2, J_CAN.2, R_CANL0.2, TP_CANL.1
CAN_L_INT: R_CANL0.1, U_CAN.6
CAN_RS: R_RS.1, U_CAN.8
CAN_RX_IC: R_CANRX.2, U_CAN.4
CAN_RX_MCU: R_CANRX.1, U_ESP.32
CAN_TX_IC: R_CANTX.2, U_CAN.1
CAN_TX_MCU: R_CANTX.1, U_ESP.29
ESP_BOOT: TP_BOOT.1, U_ESP.33
ESP_EN: TP_EN.1, U_ESP.2
ESP_VIN: D_ESP.2, U_ESP.19
GND: C_CAN.2, C_LCD.2, C_PWR1.2, C_PWR2.2, C_PWR3.2, C_SW1.2, C_SW2.2, C_SW3.2, C_SW4.2, C_SW5.2, C_SW6.2, D_CAN.2, D_GPS_ESD.2, D_SW1.2, D_SW2.2, D_SW3.2, D_SW4.2, D_SW5.2, D_SW6.2, D_TVS5.2, J_CAN.3, J_GPS.2, J_LCD.2, J_LCD.4, J_LCD.6, J_PWR.2, J_SWITCH.2, J_SWITCH.4, J_SWITCH.6, J_SWITCH.8, J_SWITCH.10, J_SWITCH.12, R_LCD_DC_PD.1, R_RS.2, TP_GND.1, U_CAN.2, U_ESP.14, U_ESP.20, U_ESP.26
GPS_PPS: J_GPS.5, TP_PPS.1
GPS_RX_MCU: R_GPS.1, U_ESP.30
GPS_TX_RAW: D_GPS_ESD.1, J_GPS.3, R_GPS.2
LCD_CS: J_LCD.9, R_LCD_CS.2
LCD_CS_MCU: R_LCD_CS.1, R_LCD_CS_PU.2, U_ESP.35
LCD_DC: J_LCD.7, R_LCD_DC.2
LCD_DC_MCU: R_LCD_DC.1, R_LCD_DC_PD.2, U_ESP.34
LCD_MOSI: J_LCD.1, R_LCD_MOSI.2
LCD_MOSI_MCU: R_LCD_MOSI.1, U_ESP.21
LCD_RST: J_LCD.5, R_LCD_RST.2
LCD_RST_MCU: R_LCD_RST.1, R_LCD_RST_PU.2, U_ESP.31
LCD_SCK: J_LCD.3, R_LCD_SCK.2
LCD_SCK_MCU: R_LCD_SCK.1, U_ESP.28
SW_GEAR_D_MCU: C_SW3.1, R_SW_PU3.1, R_SW_SER3.2, U_ESP.8
SW_GEAR_D_RAW: D_SW3.1, J_SWITCH.5, R_SW_SER3.1
SW_GEAR_R_MCU: C_SW2.1, R_SW_PU2.1, R_SW_SER2.2, U_ESP.7
SW_GEAR_R_RAW: D_SW2.1, J_SWITCH.3, R_SW_SER2.1
SW_LCD_ACTION_MCU: C_SW6.1, R_SW_PU6.1, R_SW_SER6.2, U_ESP.11
SW_LCD_ACTION_RAW: D_SW6.1, J_SWITCH.11, R_SW_SER6.1
SW_PADDOCK_MCU: C_SW5.1, R_SW_PU5.1, R_SW_SER5.2, U_ESP.10
SW_PADDOCK_RAW: D_SW5.1, J_SWITCH.9, R_SW_SER5.1
SW_STATUS_MCU: C_SW1.1, R_SW_PU1.1, R_SW_SER1.2, U_ESP.25
SW_STATUS_RAW: D_SW1.1, J_SWITCH.1, R_SW_SER1.1
SW_VESS_MCU: C_SW4.1, R_SW_PU4.1, R_SW_SER4.2, U_ESP.9
SW_VESS_RAW: D_SW4.1, J_SWITCH.7, R_SW_SER4.1
TERM_NODE: JP_TERM.1, R_TERM.2
UART0_RX: TP_RX0.1, U_ESP.24
UART0_TX: TP_TX0.1, U_ESP.23

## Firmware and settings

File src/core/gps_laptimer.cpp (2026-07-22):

#include "core/gps_laptimer.h"
#include <Arduino.h>
#include <HardwareSerial.h>
#include <math.h>
#include <stdlib.h>
#include <string.h>
#include "state.h"

namespace gps_laptimer {
namespace {
constexpr int PIN_GPS_RX = 22;      // GPS TX -> ESP32 GPIO22
constexpr int PIN_GPS_TX = -1;      // receive-only
constexpr uint32_t GPS_BAUD = 9600;
constexpr int GPS_LINE_MAX = 96;
constexpr float START_RADIUS_M = 6.0f;
constexpr float REARM_RADIUS_M = 20.0f;
constexpr uint32_t MIN_LAP_MS = 10000;
constexpr uint32_t GPS_FIX_TIMEOUT_MS = 3000;

HardwareSerial gps_serial(2);
char line[GPS_LINE_MAX];
int line_len = 0;

bool have_start = false;
bool lap_armed = false;
bool waiting_departure = false;
bool timing_active = false;
bool latest_fix = false;
double start_lat = 0.0;
double start_lon = 0.0;
double latest_lat = 0.0;
double latest_lon = 0.0;
uint32_t last_cross_ms = 0;
uint32_t last_fix_ms = 0;

int hex_value(char c) {
    if (c >= '0' && c <= '9') return c - '0';
    if (c >= 'A' && c <= 'F') return c - 'A' + 10;
    if (c >= 'a' && c <= 'f') return c - 'a' + 10;
    return -1;
}

bool checksum_ok(const char *s) {
    if (s[0] != '$') return false;
    const char *star = strchr(s, '*');
    if (!star) return true;

    uint8_t sum = 0;
    for (const char *p = s + 1; p < star; ++p) sum ^= (uint8_t)*p;

    int hi = hex_value(star[1]);
    int lo = hex_value(star[2]);
    if (hi < 0 || lo < 0) return false;
    return sum == (uint8_t)((hi << 4) | lo);
}

double deg_min_to_decimal(const char *value, char hemi) {
    if (!value || !value[0]) return 0.0;
    const double raw = atof(value);
    const int deg = (int)(raw / 100.0);
    const double minutes = raw - (double)deg * 100.0;
    double decimal = (double)deg + minutes / 60.0;
    if (hemi == 'S' || hemi == 'W') decimal = -decimal;
    return decimal;
}

float distance_m(double lat1, double lon1, double lat2, double lon2) {
    constexpr double R = 6371000.0;
    constexpr double DEG2RAD_LOCAL = 0.017453292519943295;
    const double p1 = lat1 * DEG2RAD_LOCAL;
    const double p2 = lat2 * DEG2RAD_LOCAL;
    const double dlat = (lat2 - lat1) * DEG2RAD_LOCAL;
    const double dlon = (lon2 - lon1) * DEG2RAD_LOCAL;
    const double x = dlon * cos((p1 + p2) * 0.5);
    return (float)(sqrt(x * x + dlat * dlat) * R);
}

void update_lap(double lat, double lon) {
    const uint32_t now = millis();
    state.gps_fix_ok = true;
    latest_fix = true;
    latest_lat = lat;
    latest_lon = lon;
    last_fix_ms = now;

    if (!have_start) {
        return;
    }

    const float dist = distance_m(start_lat, start_lon, lat, lon);
    if (waiting_departure) {
        state.current_lap_ms = 0;
        if (dist >= START_RADIUS_M) {
            waiting_departure = false;
            timing_active = true;
            lap_armed = false;
            last_cross_ms = now;
        }
        return;
    }

    if (!timing_active || last_cross_ms == 0) return;

    state.current_lap_ms = now - last_cross_ms;

    if (dist >= REARM_RADIUS_M) {
        lap_armed = true;
    }

    if (lap_armed && dist <= START_RADIUS_M && now - last_cross_ms >= MIN_LAP_MS) {
        const uint32_t lap_ms = now - last_cross_ms;
        const uint8_t completed_lap = state.lap_count < 99 ? (uint8_t)(state.lap_count + 1) : 99;
        state.last_lap_ms = lap_ms;
        if (state.best_lap_ms == 0 || lap_ms < state.best_lap_ms) {
            state.best_lap_ms = lap_ms;
            state.best_lap_count = completed_lap;
        }
        state.current_lap_ms = 0;
        last_cross_ms = now;
        if (state.lap_count < 99) ++state.lap_count;
        lap_armed = false;
    }
}

void parse_rmc(char *sentence) {
    if (!checksum_ok(sentence)) return;

    char *star = strchr(sentence, '*');
    if (star) *star = '\0';

    char *fields[16] = {};
    int count = 0;
    char *p = sentence[0] == '$' ? sentence + 1 : sentence;
    fields[count++] = p;
    while (*p && count < 16) {
        if (*p == ',') {
            *p = '\0';
            fields[count++] = p + 1;
        }
        ++p;
    }

    if (count < 7) return;
    if (strcmp(fields[0], "GPRMC") != 0 && strcmp(fields[0], "GNRMC") != 0) return;
    if (fields[2][0] != 'A') {
        state.gps_fix_ok = false;
        latest_fix = false;
        last_fix_ms = 0;
        return;
    }

    const double lat = deg_min_to_decimal(fields[3], fields[4][0]);
    const double lon = deg_min_to_decimal(fields[5], fields[6][0]);
    update_lap(lat, lon);
}

void consume_char(char c) {
    if (c == '\r') return;
    if (c == '\n') {
        line[line_len] = '\0';
        if (line_len > 6) parse_rmc(line);
        line_len = 0;
        return;
    }

    if (line_len < GPS_LINE_MAX - 1) {
        line[line_len++] = c;
    } else {
        line_len = 0;
    }
}
}

void begin() {
    gps_serial.begin(GPS_BAUD, SERIAL_8N1, PIN_GPS_RX, PIN_GPS_TX);
}

void poll() {
    while (gps_serial.available() > 0) {
        consume_char((char)gps_serial.read());
    }

    if (latest_fix && millis() - last_fix_ms > GPS_FIX_TIMEOUT_MS) {
        state.gps_fix_ok = false;
        latest_fix = false;
    }
}

bool start_at_current_fix() {
    if (!latest_fix) return false;

    start_lat = latest_lat;
    start_lon = latest_lon;
    have_start = true;
    lap_armed = false;
    waiting_departure = true;
    timing_active = false;
    last_cross_ms = 0;
    state.lap_count = 0;
    state.current_lap_ms = 0;
    state.last_lap_ms = 0;
    state.best_lap_count = 0;
    state.best_lap_ms = 0;
    return true;
}

void stop() {
    have_start = false;
    lap_armed = false;
    waiting_departure = false;
    timing_active = false;
    last_cross_ms = 0;
    state.current_lap_ms = 0;
}
}

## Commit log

2026-06-30 feat(cluster): hmi_input module (buttons -> mode/reset)
    Implement `hmi_input` TDD with 5 passing tests. Button bit0 (rising edge)
    cycles drive_mode 0->1->2->0; bit1 (rising edge) sets reset_req flag.
    Pure module using explicit state params (no globals).
2026-06-30 feat(cluster): MCP23017 io_expander driver (locked)
2026-06-30 feat(cluster): app wiring + entry point; full ESP32 build green
2026-06-30 fix(cluster): pin platform, correct ADDING_A_MODULE for Cluster, clear reset_req latch
    - platformio.ini: pin espressif32 @ 7.0.1 (Arduino core 2.0.17, channel LEDC API)
    - docs/ADDING_A_MODULE.md: VehicleState→ClusterState, imu.h→hmi_input.h example, relax Percent type checklist item
    - src/core/app_wiring.cpp: clear state.reset_req after send_command (one-shot latch)
2026-07-02 feat(cluster): 1bpp FrameBuffer + drawing primitives (clip, rect, bar)
2026-07-02 feat(cluster): widget_gear (R/N/D)
    TDD test-first implementation:
    - widget_gear_draw(): draws gear letter (0=N, 1=R, 2=D) at (x,y) scale 3
    - unknown gear returns blank
    - 2 tests: each valid gear draws, invalid gear blank
2026-07-02 feat(cluster): ClusterCommand contract + hmi_input rework (gear/mode/paddock)
2026-07-02 feat(cluster): encode ClusterCommand to 0x1801D0C0 frame
2026-07-02 feat(cluster): display_blit stub + can_bus send_command(ClusterCommand)
2026-07-02 feat(cluster): rewire app_wiring to framebuffer widgets + ClusterCommand; ESP32 build green
    Rewrites the locked app_wiring.cpp to consume the new FrameBuffer/widget
    stack (Tasks 3-6), hmi_compute+ClusterCommand (Task 7), and
    can_bus/display_blit (Task 10) instead of the removed U8g2 display,
    io_expander, indicators, and vess modules.
    - hmi_update: direct GPIO (gear R/D pins + paddock switch) -> hmi_compute
    -> ClusterCommand -> can_bus::send_command
    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
2026-07-02 chore(cluster): prune unused lib_deps; refresh README/CLAUDE docs; comment battery layout
2026-07-02 docs(cluster): de-stale README (stack, test count, display_blit)
2026-07-02 docs(cluster): CAN_PROTOCOL 5.7 command layout matches encode_cluster_command (gear/mode/paddock)
2026-07-03 docs(cluster): add version history (Changelog) — v1.0, v1.1
2026-07-10 chore(cluster): CODEOWNERS — core paths require team-lead review
2026-07-14 docs: 테스트 주석 추가 (#1)
2026-07-15 MCU to VCU can poll_rx 추가 (#3)
    * docs: 테스트 주석 추가
    * docs: 코어 수정 테스트
    * feat(cluster): sniff MCU->VCU feedback frames for dual motor state
    Controllers stay in VCU mode; Cluster passively reads the VCU-addressed
    feedback frames (0x1801D0xx/0x1802D0xx) off the shared CAN bus instead of
    using METER mode or a VCU gateway rebroadcast (CAN_PROTOCOL.md §7).
    - can_protocol.h: add CAN_ID_FB1_R/FB2_R (Controller_R)
    - state.h: add _r-suffixed fields mirroring Controller_R
    - can_bus.cpp: implement poll_rx() decoding of FB1/FB2 into state
2026-07-22 김민철 (#4)
    * Implement ILI9341 cluster display and BLE BMS
    * Harden cluster telemetry stale handling
    * feat(cluster): add VESS enable switch command
    * feat(cluster): update LCD diagnostics and BMS parsing
    * tune(cluster): reduce lap trigger radius
    * fix(cluster): move status switch to gpio21
    * feat(cluster): show BMS status on check page
    * feat(cluster): improve vehicle check page readability
    * feat(cluster): simplify vehicle check page
    * feat(hardware): add KiCad RevA project and DRC workflow
    * fix(cluster): remove VESS GPIO command input
    * feat(cluster): align pin map with PCB wiring PDF
    * feat(cluster): broadcast BMS telemetry over CAN
    [HEVEN_Cluster_RevA.kicad_pcb]
